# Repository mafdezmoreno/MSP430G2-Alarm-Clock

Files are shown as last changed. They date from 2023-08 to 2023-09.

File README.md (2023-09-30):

# MSP430G2-Alarm-Clock

## Introduction

## Hardware Requirements

 - MCU: msp430g2553 or similar (with enough memory).
 - External low frequency clock (32768Hz).
 - PCB, proto board, something to build the circuit.
 - Programmer. In my case I'm using the programmer of a launchpad.

Warning: LaunchPads with eZ430-RF2500 will not work with linux or mac, look for launchpads with eZ-FET interface.

### Functions Implemented

 - [X] Clock
 - [X] Date
 - [X] Alarm
 - [X] Control to set clock time and date time.
 - [X] Control to set alarm
 - [X] Battery level monitoring
 - [X] Humidity and temperature with dht sensor
 - [X] Auto lcd light on if some button is pushed
 - [X] Low power mode. This mode reduces minimum power consumption from 0.71mA to 0.33mA

## Compiling the Code

There are two principal compiler options:
 * Ti Compiler, included in [CSStudio IDE](https://www.ti.com/tool/CCSTUDIO) (recommended).
 * [GNU Compiler](https://www.ti.com/tool/MSP430-GCC-OPENSOURCE) 

The best way to avoid problems is use CSStudio and Ti compiler. Trying another options can ba a frustrating process.

Anyway, I prefer to generate/update the makefile with CSS and then work with Clion or VSCode.

I've also tried to create a cMake projects, based on [AlexanderSidorenko repo](https://github.com/AlexanderSidorenko/msp-cmake), but with no success by now.

## Flashing the MCU
There are several tools to flash the compiled code into the MSC:
 * Code Composer Studio, which uses internally MSP430Flasher (recommended).
 * [MSP430Flasher](https://www.ti.com/tool/MSP430-FLASHER) cl software and your favourite text editor (more work). A 'upload' make argument can be manually placed inside the CSS generated makefile.
 * [mspdebuger](https://dlbeer.co.nz/mspdebug/). This was my favourite in the past, but I was unable to make in work, maybe mspdebuger is not compatible with current TI compiler.

[More info about upload code using MSP430Flasher here](https://github.com/mafdezmoreno/Testing_MSP430G2)

### Hardware Connections:

Connect the following signals from the debugger to the target MCU.

 * 3.3V
 * GND
 * SBWTDIO
 * SBWTCK

## Schematics and PCB

A Kicad project is included in this repo. This projects include schematics and PCB.

Todo:
 - [X] Review of connections
 - [X] PCB Design
 - [X] Gerber files generation and PCB ordering.

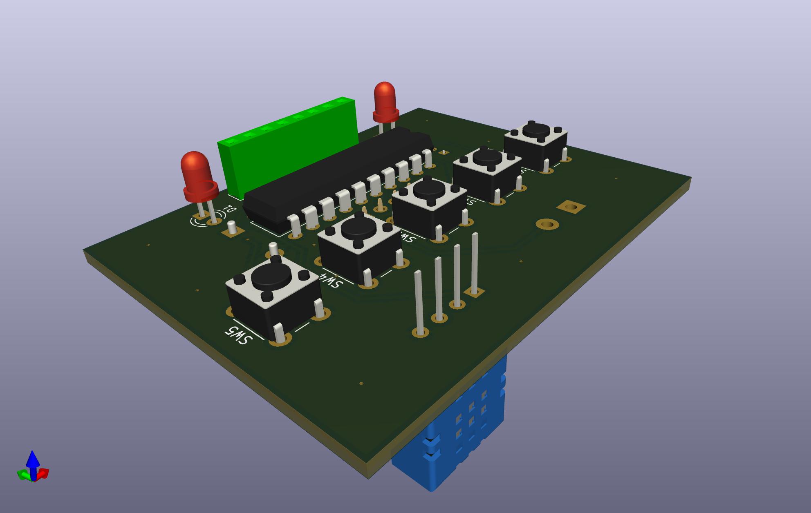
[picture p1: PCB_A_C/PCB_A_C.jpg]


## Other Comments and Problems Working With MSP430

The real time operations can be affected for encapsulation and compiler configuration and introduce in the compiled code unexpected delays. The solution can involve simplify the code (reduce encapsulation to make it "easier" to the compiler) and/or tune the compiler settings.

# Useful resources

 - [MSP430F2xx, MSP430G2xx Family User’s Guide](https://www.ti.com/lit/ug/slau144k/slau144k.pdf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)
 - [MSP Flasher User’s Guide](https://www.ti.com/lit/ug/slau654e/slau654e.pdf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)
 - [MSP430 Optimizing C/C++ Compiler v21.6.0.LTS](https://www.ti.com/lit/ug/slau132y/slau132y.pdf?ts=1695037938667)
 - [MSP430G2x53 datasheet](https://www.ti.com/lit/ds/symlink/msp430g2553.pdf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)

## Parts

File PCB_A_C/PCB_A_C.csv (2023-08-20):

# | Reference | Qty | Value | Footprint | DNP
1 | BZ1 | 1 | Buzzer | Buzzer_Beeper:Buzzer_12x9.5RM7.6
2 | C1 | 1 | C | Capacitor_THT:CP_Radial_D4.0mm_P2.00mm
3 | D1, D2 | 2 | LED | LED_THT:LED_D3.0mm
4 | J1 | 1 | Conn_01x08_Socket | Connector_Harwin:Harwin_M20-89008xx_1x08_P2.54mm_Horizontal
5 | J2 | 1 | Conn_01x04 | Connector_Harwin:Harwin_M20-89004xx_1x04_P2.54mm_Horizontal
6 | J3 | 1 | Screw_Terminal_01x02 | TerminalBlock_MetzConnect:TerminalBlock_MetzConnect_Type701_RT11L02HGLU_1x02_P6.35mm_Horizontal
7 | R1 | 1 | 47k | Resistor_SMD:R_1210_3225Metric_Pad1.30x2.65mm_HandSolder
8 | R2, R3 | 2 | R | Resistor_SMD:R_1210_3225Metric_Pad1.30x2.65mm_HandSolder
9 | SW1, SW2, SW3, SW4, SW5 | 5 | SW_Push | Button_Switch_THT:SW_DIP_SPSTx01_Slide_6.7x4.1mm_W7.62mm_P2.54mm_LowProfile
10 | U1 | 1 | DHT11 | Sensor:Aosong_DHT11_5.5x12.0_P2.54mm
11 | U2 | 1 | MSP430G2553IN20 | Package_DIP:DIP-20_W7.62mm
12 | Y0 | 1 | 32kHz | Crystal:Crystal_DS26_D2.0mm_L6.0mm_Vertical

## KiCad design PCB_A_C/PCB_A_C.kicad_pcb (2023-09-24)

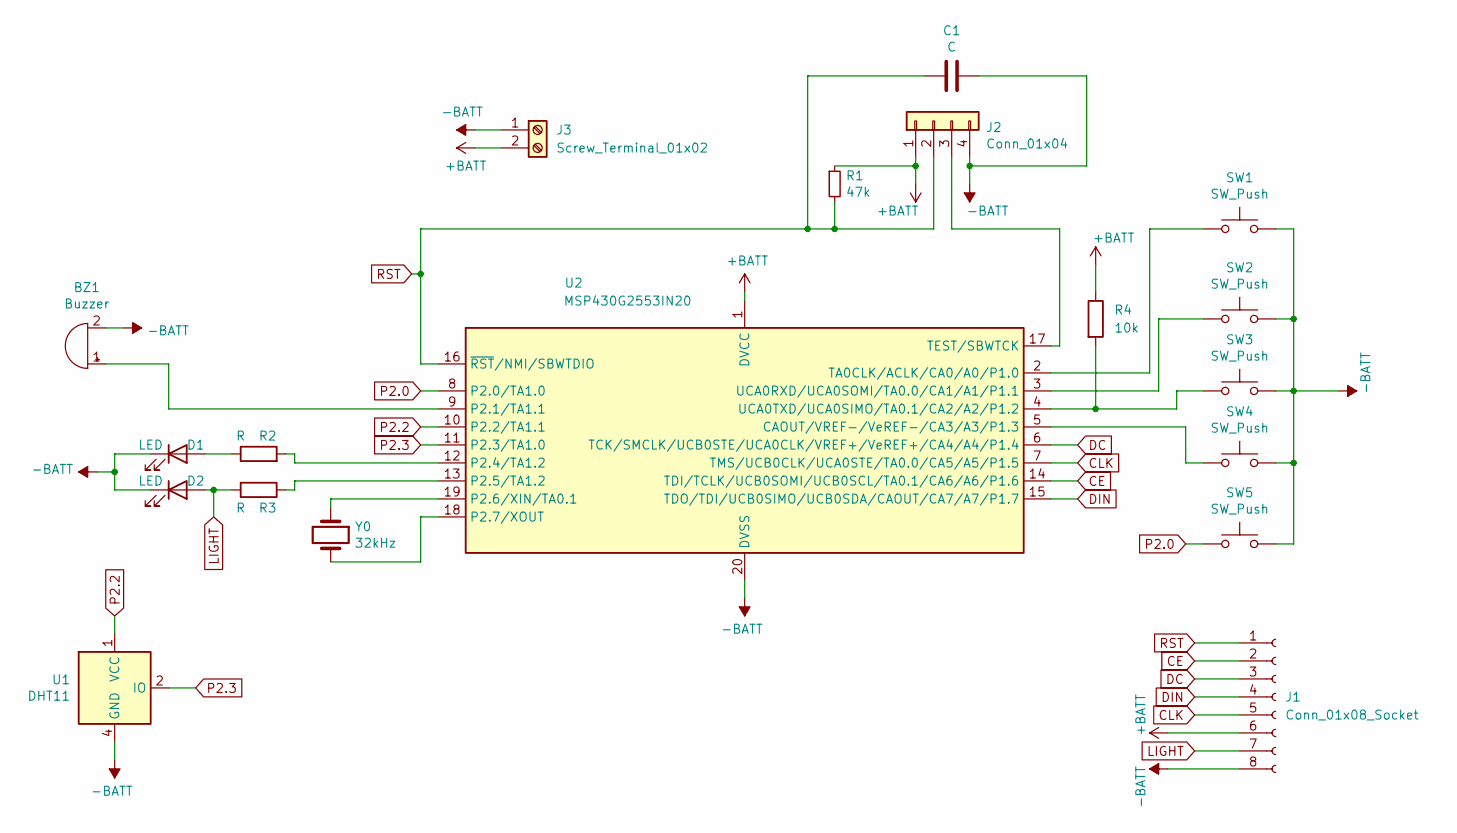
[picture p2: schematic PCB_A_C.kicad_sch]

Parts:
BZ1: Buzzer; Buzzer_12x9.5RM7.6
C1: C; CP_Radial_D4.0mm_P2.00mm
D1, D2: LED; LED_D3.0mm
J1: Conn_01x08_Socket; PinSocket_1x08_P2.54mm_Vertical
J2: Conn_01x04; PinSocket_1x04_P2.54mm_Vertical
J3: Screw_Terminal_01x02; TerminalBlock_MetzConnect_Type101_RT01602HBWC_1x02_P5.08mm_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
R1: 47k; R_1210_3225Metric_Pad1.30x2.65mm_HandSolder
R2, R3: R; R_1210_3225Metric_Pad1.30x2.65mm_HandSolder
R4: 10k; R_1210_3225Metric_Pad1.30x2.65mm_HandSolder
SW1, SW2, SW3, SW4, SW5: SW_Push; SW_PUSH_6mm
U1: DHT11; Aosong_DHT11_5.5x12.0_P2.54mm
U2: MSP430G2553IN20; DIP-20_W7.62mm
Y0: 32kHz; Crystal_DS26_D2.0mm_L6.0mm_Vertical

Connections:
+BATT: J1.6, J2.1, J3.2, R1.1, R4.1, U2.1 (DVCC)
-BATT: BZ1.2 (+), C1.1, D1.1 (K), D2.1 (K), J1.8, J2.4, J3.1, SW1.2, SW2.2, SW3.2, SW4.2, SW5.2, U1.4 (GND), U2.20 (DVSS)
CE: J1.2, U2.14 (TDI/TCLK/UCB0SOMI/UCB0SCL/TA0.1/CA6/A6/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)
CLK: J1.5, U2.7 (TMS/UCB0CLK/UCA0STE/TA0.0/CA5/A5/P1.5)
DC: J1.3, U2.6 (TCK/SMCLK/UCB0STE/UCA0CLK/VREF+/VeREF+/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)
DIN: J1.4, U2.15 (TDO/TDI/UCB0SIMO/UCB0SDA/CAOUT/CA7/A7/P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)
LIGHT: D2.2 (A), J1.7, R3.2
unnamed: BZ1.1 (-), U2.9 (P2.1/TA1.1)
unnamed: D1.2 (A), R2.1
unnamed: J2.3, U2.17 (TEST/SBWTCK)
unnamed: SW4.1, U2.5 (CAOUT/VREF-/VeREF-/CA3/A3/P1.3)
unnamed: R2.2, U2.12 (P2.4/TA1.2)
unnamed: R3.1, U2.13 (P2.5/TA1.2)
unnamed: U2.19 (P2.6/XIN/TA0.1), Y0.1
unnamed: U2.18 (P2.7/XOUT), Y0.2
unnamed: SW1.1, U2.2 (TA0CLK/ACLK/CA0/A0/P1.0)
unnamed: SW2.1, U2.3 (UCA0RXD/UCA0SOMI/TA0.0/CA1/A1/P1.1)
unnamed: R4.2, SW3.1, U2.4 (UCA0TXD/UCA0SIMO/TA0.1/CA2/A2/P1.2)
P2.0: SW5.1, U2.8 (P2.0/TA1.0)
P2.2: U1.1 (VCC), U2.10 (P2.2/TA1.1)
P2.3: U1.2 (IO), U2.11 (P2.3/TA1.0)
RST: C1.2, J1.1, J2.2, R1.2, U2.16 (~RST/NMI/SBWTDIO)

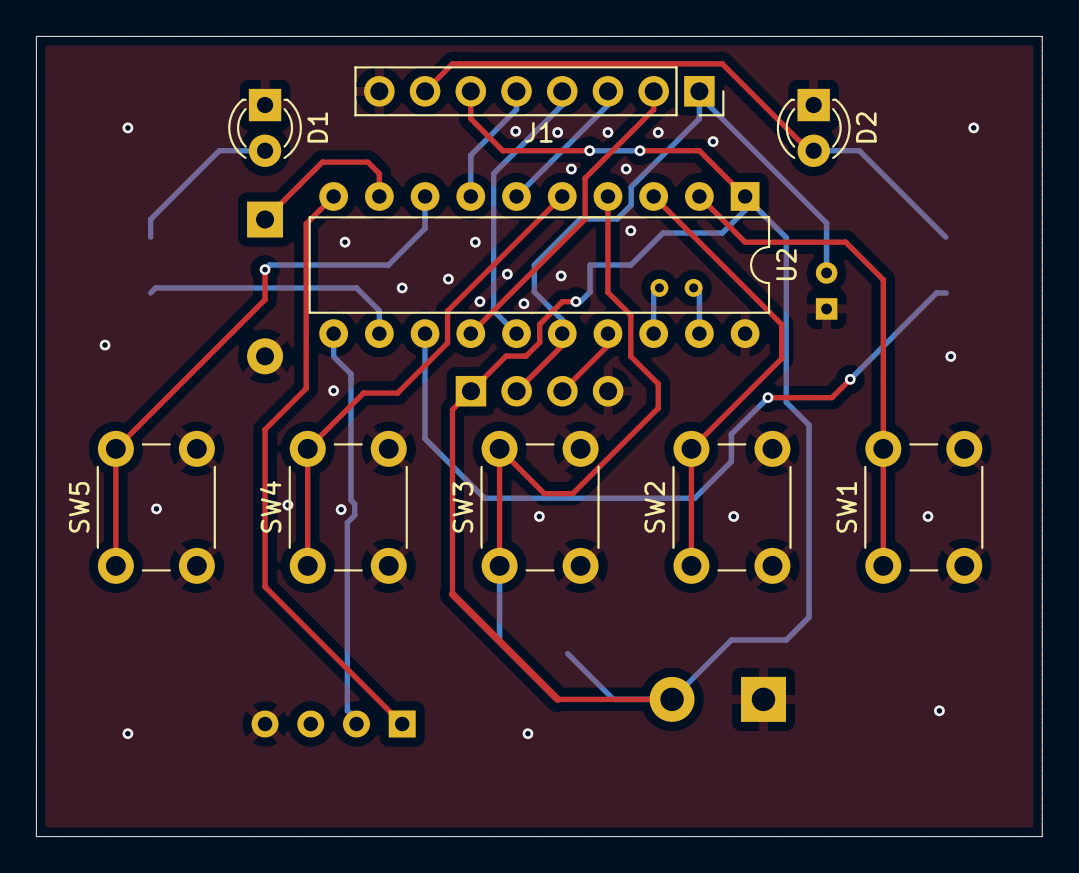
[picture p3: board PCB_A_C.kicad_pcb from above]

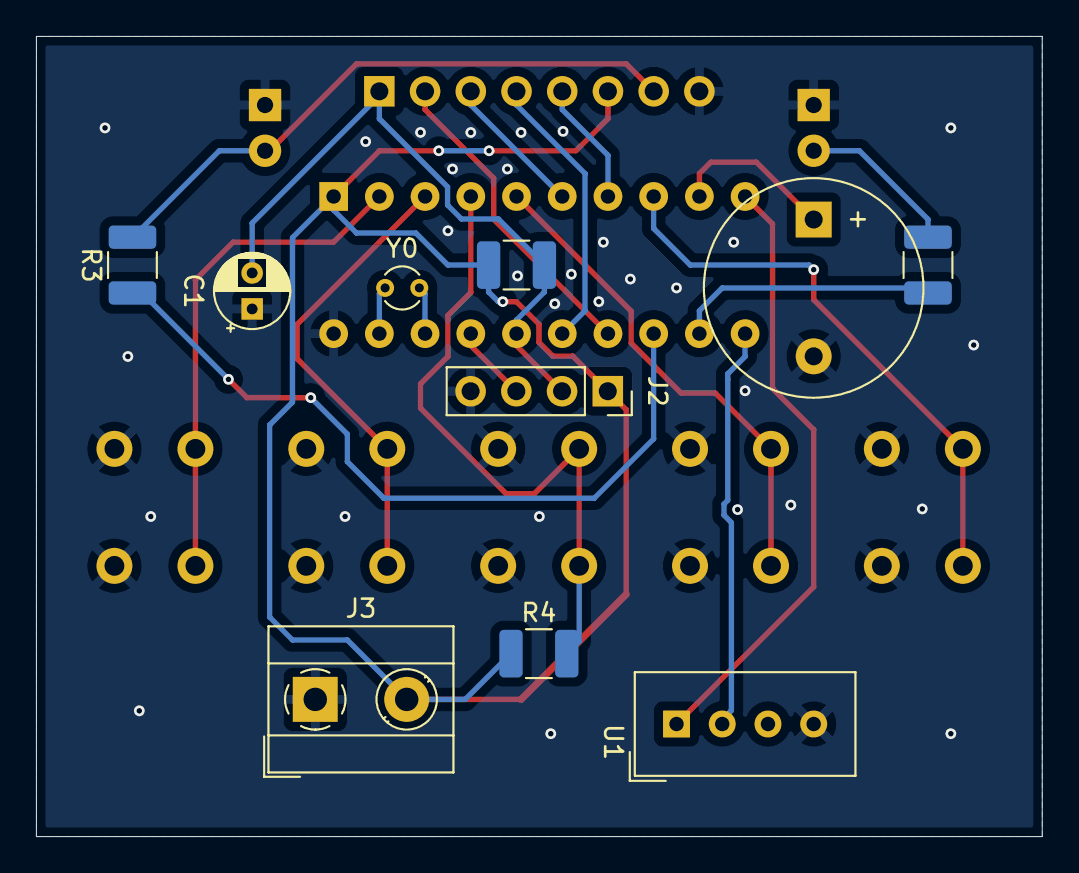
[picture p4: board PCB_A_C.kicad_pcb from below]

Board: 2 copper layers, 55.9 x 44.4 mm, 19 parts (10 on the bottom side), 22 nets.

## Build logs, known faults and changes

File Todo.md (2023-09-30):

# To do

## 25/09/2023

- [X] Define position (hour, minutes, seconds, day...) on the LCD to fix it and use this const in several functions.
- [X] Implement the value change for every value (so far it's only implemented with hour's value).
- [X] Alarm and buzzer.
- [X] Alarm days activation.
- [X] Analog read to check battery level.
- [X] Dht to show temperature and humidity.
- [X] Low power mode, to save battery.

## 30/09/2023
- [X] Correct moth increments with the number of days of each month.
- [ ] Remove loops delays.
- [ ] Add some function to the LED (previously used as debug tool)
- [ ] Improve encapsulation. Move remaining isolated functions inside classes.
- [ ] Correct push buttons positions.
- [ ] Review of date class and implement date struct type.
- [ ] Remove unused methods and cleaning.

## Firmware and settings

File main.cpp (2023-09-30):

#define LOW_POWER

#include "buzzer.h"
#include "buzzerTimer.h"
#include "clockTimer.h"
#include "lcdInterface.h"
#include "msp430g2553.h"
#include "timeDate.h"
#include "alarm.h"
#include "dht.h"
#include "io.h"

void initMcu();
unsigned signalIncrementSec = 0;
clockTimer ct;
buzzer buz(&ct);
void buzzerControl();

int main()
{
    static bool signalIncrementMin = false;
    static unsigned signalButton = 0;

    initMcu();
    timeDate td(&signalIncrementMin);
    buttons but;
    dht d;
    alarm al1(td.getCurrentTime(), td.getCurrentWeekDay());
    alarm al2(td.getCurrentTime(), td.getCurrentWeekDay());
    lcdLight light;

    // TODO: testing:
    enableLed();
    ledOff();
    light.on(); // Todo: To remove after tests
    __delay_cycles(200000);
    // End Testing part

    lcdInterface li(&td, &al1, &al2, &but, &d);
    while (true)
    {
        static bool alarmStarted = false;
        if (signalIncrementSec)
        {
            while (signalIncrementSec)
            {
                td.incrementSecond();
                signalIncrementSec--;
            }
            d.readDht();
            li.printAll();
            light.countDown();
        }
        if (signalIncrementMin)
        {
            signalIncrementMin = false;
            static unsigned minCounter = 0;
            if (!alarmStarted && (al1.alarmTimeNow() || al2.alarmTimeNow()))
            {
                minCounter = 0;
                buz.activeBuz();
                alarmStarted = true;
            } else if (minCounter >= 5 && alarmStarted)
            {  // alarm can be on for 5 minutes.
                buz.deactivateBuz();
                minCounter = 0;
                alarmStarted = false;
            }
            minCounter++;
            li.batteryLevelToLcd();
        }
        signalButton = but.getSignalButton();
        switch (signalButton)
        {
            case 1:
                break;
            case 2:
                break;
            case 4:
                li.changeTime();
                break;
            case 8:
                li.changeAlarm();
                break;
            case 16:
                break;
        }
        switch (signalButton)
        {
            case 1:
            case 2:
            case 4:
            case 8:
            case 16:
                buz.deactivateBuz();
                alarmStarted = false;
                light.resetCounter();
        }
#ifdef LOW_POWER
        __bis_SR_register(LPM3_bits);
#else
        ct.delay(500);
#endif
    }
}

//Timer ISR to increment seconds
#pragma vector = TIMER0_A0_VECTOR
__interrupt void timerA0(void)
{
    static unsigned long counter = 0;

    if (buz.getBuzActive())
    {
        if (counter == 256)
        {
            signalIncrementSec++;
            counter = 0;
        }
        counter++;
        buzzerControl();
    }
    else
    {
        signalIncrementSec++;
    }
#ifdef LOW_POWER
    __bic_SR_register_on_exit(LPM3_bits);
#endif
}

void initMcu()
{
    WDTCTL = WDTPW + WDTHOLD; //Stop watchdog timer

    //MCLK=SMCLK=1Mhz
    //DCOCTL, DCO Control Register
    DCOCTL = 0;            //clears DCOCTL to set the DCOCLK to the lowest setting.
    DCOCTL = CALDCO_1MHZ;  //Copy the calibration data

    //BCSCTL1, Basic Clock System Control Register 1
    BCSCTL1 = CALBC1_1MHZ; //Copy the calibration data

    __bis_SR_register(GIE); // Enable interrupts
}

void buzzerControl()
{
    static unsigned start = 0;
    static const unsigned stop = 40;

        if (start < 2 * stop)
        {
            buz.makeSound();
            start++;
        }
        else if (start < 3 * stop)
        {
            start++;
        }
        else if (start < 5 * stop)
        {
            buz.makeSound();
            start++;
        }
        else if (start < 10 * stop)
        {
            start++;
        }
        else
        {
            start = 0;
        }
}

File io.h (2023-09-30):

#ifndef IO_H_
#define IO_H_

#include "msp430g2553.h"

#define DISPLAY_LED_PORT 2
#define DISPLAY_LED_BIT BIT5

#define LED_PORT 2
#define LED_BIT BIT4

void ledOff();
void ledOn();
void toggleLed();
void enableLed();

class lcdLight
{
public:
    lcdLight();
    void off();
    void on();
    void countDown();
    void resetCounter();
private:
    unsigned counter;
    void enable();
    void disable();
};

#endif /* IO_H_ */

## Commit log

2021-06-12 KiCAD Schematic
    [PCB_A_C.kicad_pcb, PCB_A_C.sch]
2023-08-17 Minor correction, renaming problematic name variables (interference in substitutions)
    [main.cpp]
2023-08-17 CCS makefiles for the current source files
2023-08-17 Integrated timer changes for future buzzer sound alarm functionality.
    [main.cpp]
2023-08-17 Added buzzer activation class and management to correctly generate the frequency to feed it in callback timer.
    [main.cpp]
2023-08-18 Refactored button class. Improved delays.
2023-08-18 Corrected eventual unordered date printing.
2023-08-20 Corrected minors errors on schematic and generated initial PCB version only with components positioned (not routed).
    [PCB_A_C.csv, PCB_A_C.kicad_pcb, PCB_A_C.kicad_sch]
2023-08-21 Routed PCB.
    [PCB_A_C.kicad_pcb]
2023-08-22 Corrected connector position on PCB.
    [PCB_A_C.kicad_pcb]
2023-08-27 Changes to allow alarm class have access to week day and current time.
2023-08-27 New management for buttons clicks. Implemented initial communication between time, alarm and buttons classes.
2023-08-27 Updated gitignore to include symbolic links. Minor correction.
    [main.cpp]
2023-08-31 Improved (safer) time-date to lcd print
2023-08-31 Seconds don't pause if some button is pushed
2023-08-31 Corrected mechanism to start and stop a preset alarm.
    [main.cpp]
2023-09-24 Implemented battery level monitor. Updated readme
    [PCB_A_C.kicad_pcb, PCB_A_C.kicad_sch]
2023-09-24 Added timer 1 class
2023-09-24 Added dht sensor to code
2023-09-30 Display led function with auto-deactivation mode
2023-09-30 Clock timer variable recurring interrupts if function of alarms (buzzer) activations.
    [main.cpp]
2023-09-30 Low power mode added. Documented pending tasks.
